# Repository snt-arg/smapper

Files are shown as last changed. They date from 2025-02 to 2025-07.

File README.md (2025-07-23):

<div align="center">
  <h1>🗺️ SMapper: A Portable Multimodal Sensing Platform</h1>
</div>

SMapper is a portable multimodal sensing platform designed for robotics research. It is equipped with an on-board computer, a 3D LiDAR, a set of 4 RGB cameras and a depth camera.

For more information, please visit the online documentation [here](https://snt-arg.github.io/smapper_docs/)

> [!NOTE]
> This device is the result of a Master's thesis conducted by Pedro Soares.

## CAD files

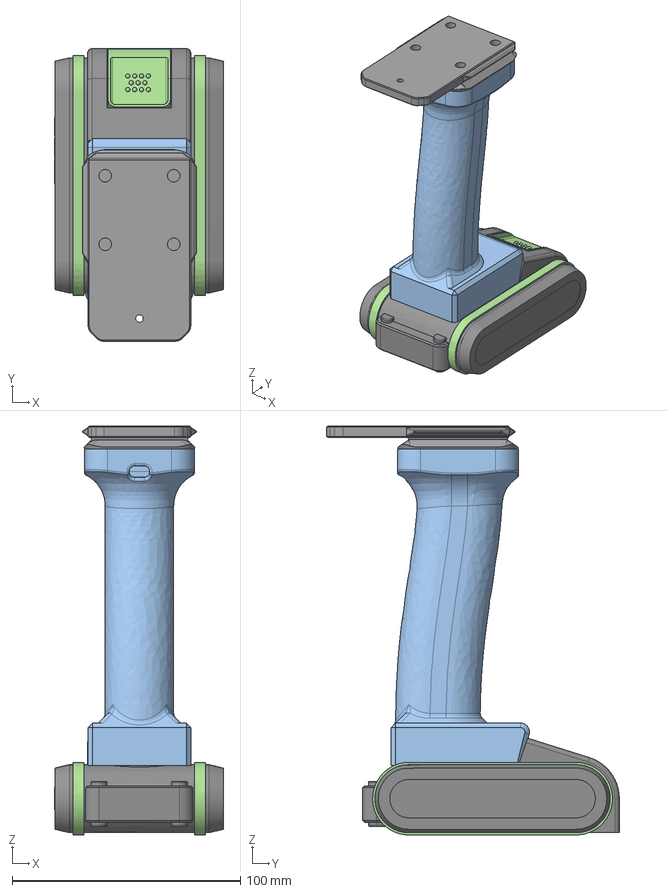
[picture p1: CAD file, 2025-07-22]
hardware/STEP/Battery Handle Assembly.step
74.0 x 128.1 x 179.0 mm
Works 20v Battery v2 v1 x 5
Locking base
Text - 20V x 3
Handle

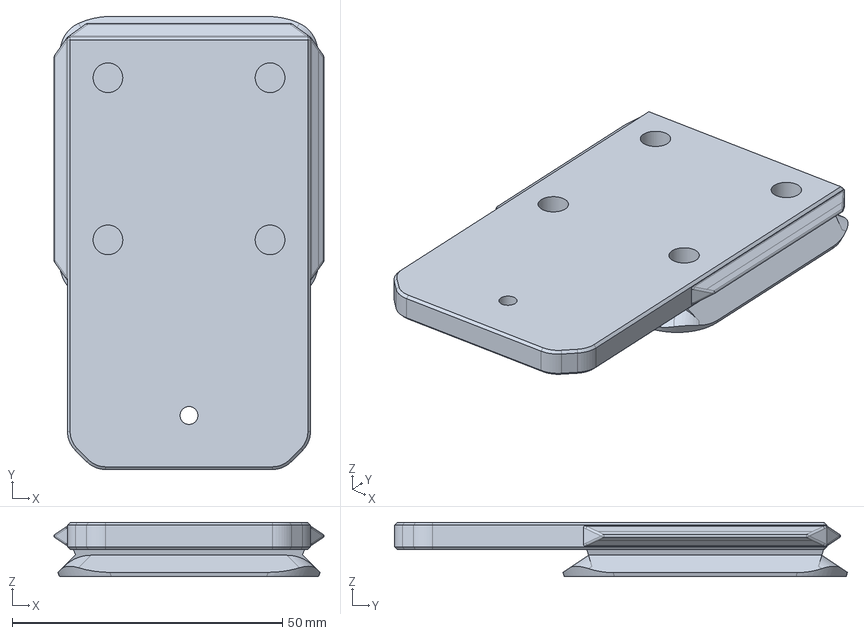
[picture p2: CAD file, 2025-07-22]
hardware/STEP/DovetailMale.step
49.9 x 83.8 x 10.0 mm

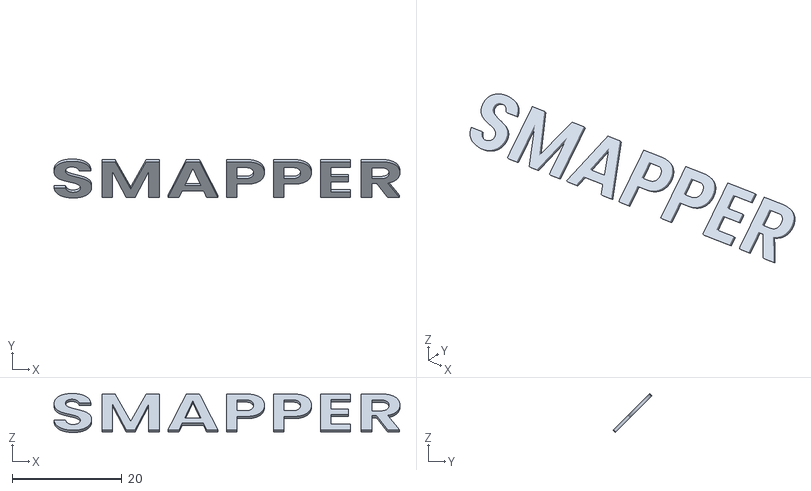
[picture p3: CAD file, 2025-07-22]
hardware/STL/EnclosureLetters.stl
63.2 x 7.14 x 7.14

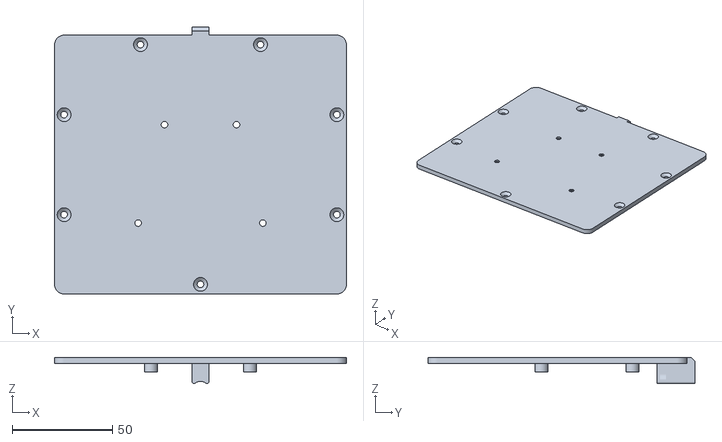
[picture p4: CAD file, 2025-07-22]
hardware/STL/EnclosureTopPlateBasic.stl
146.0 x 133.4 x 13.1

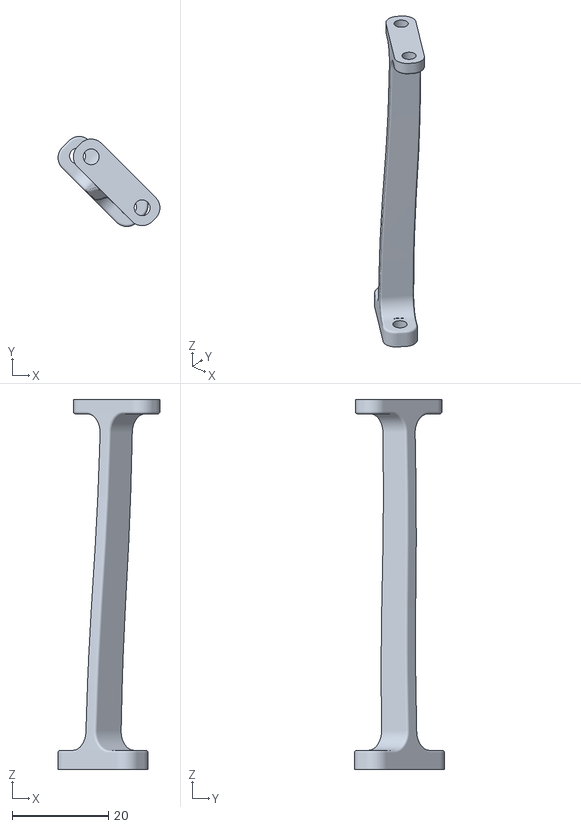
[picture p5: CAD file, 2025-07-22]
hardware/STL/LidarCageFrontLeg.stl
21.2 x 18.7 x 77.0

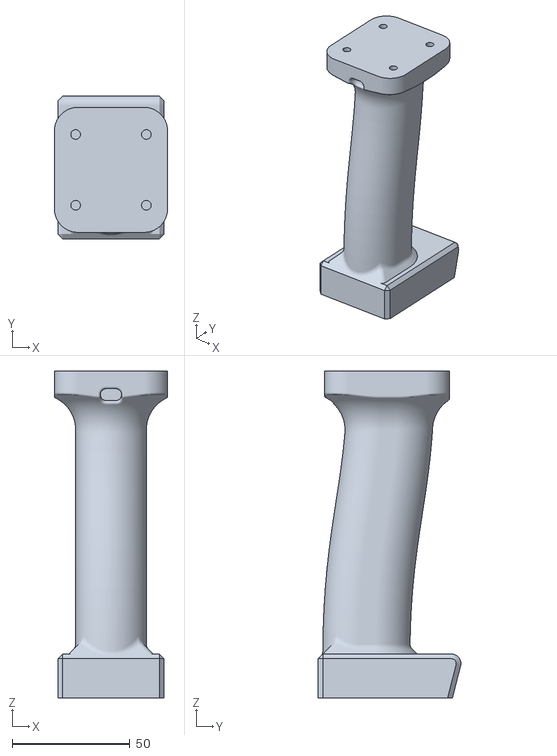
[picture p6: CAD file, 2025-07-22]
hardware/STL/Handle.stl
48.0 x 60.6 x 138.6

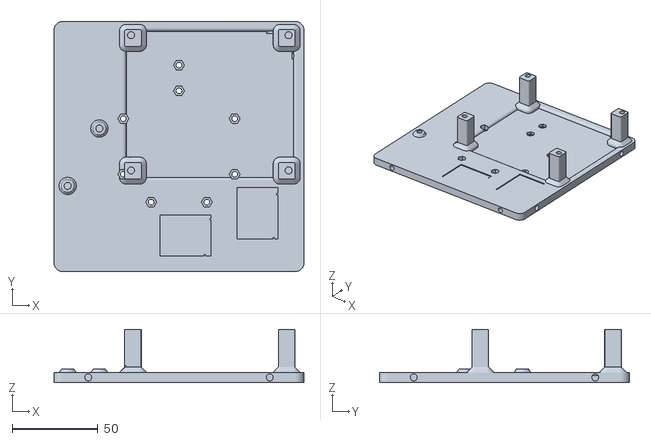
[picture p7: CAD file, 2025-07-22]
hardware/STL/EnclosureBasePlate.stl
146.0 x 146.0 x 31.0

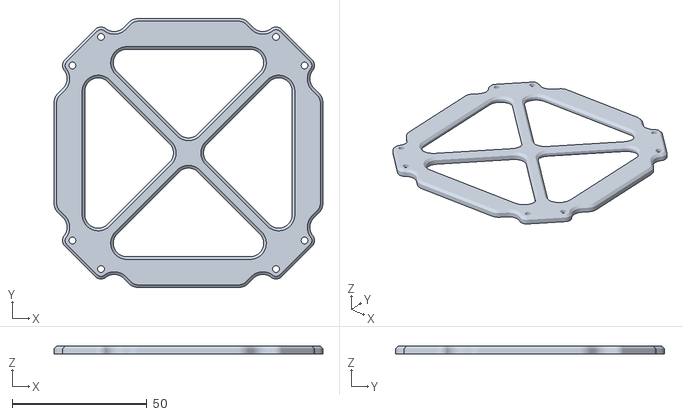
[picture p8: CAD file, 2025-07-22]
hardware/STL/LidarCageTopPlate.stl
100.0 x 100.0 x 3.00

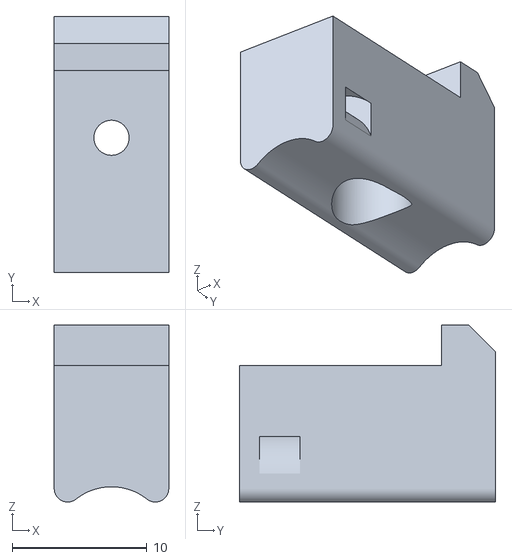
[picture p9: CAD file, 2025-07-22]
hardware/STL/EnclosureOusterCableSupport-MetalPlate.stl
8.50 x 19.0 x 13.1

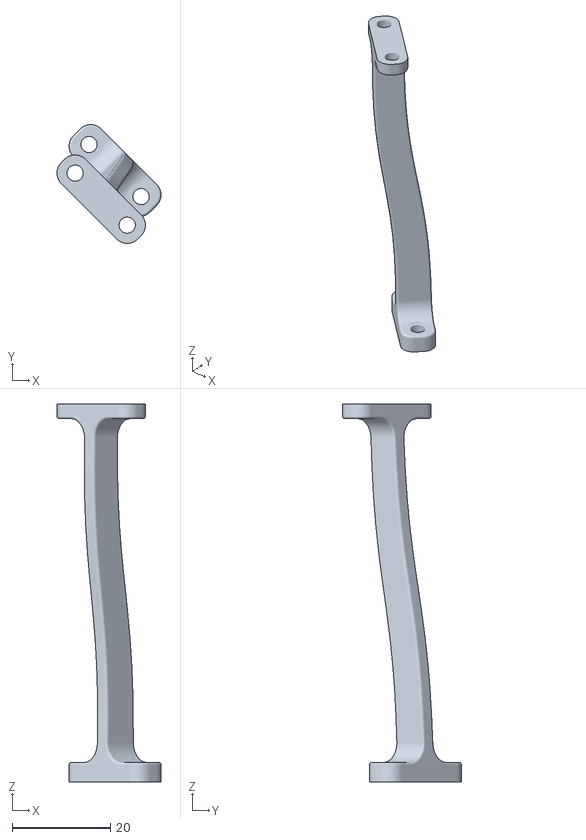
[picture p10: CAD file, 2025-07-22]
hardware/STL/LidarCageBackLeg.stl
21.2 x 24.2 x 77.0

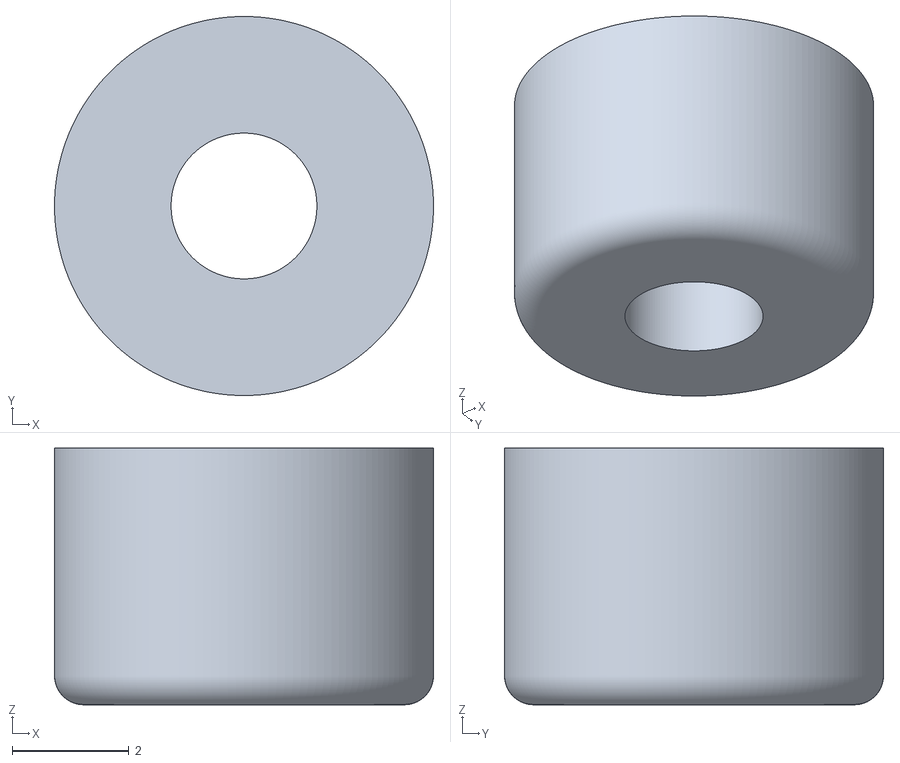
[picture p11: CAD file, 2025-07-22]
hardware/STL/EnclosureOusterInterfaceBoxSpacer-MetalPlate.stl
6.50 x 6.50 x 4.40

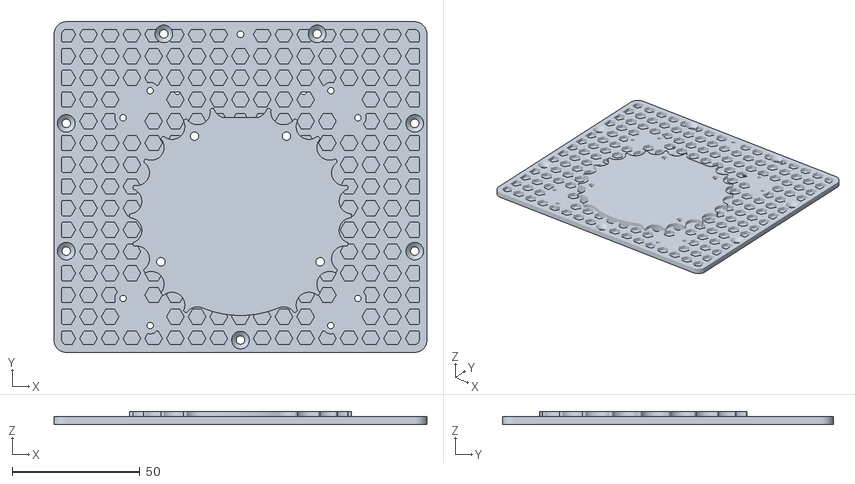
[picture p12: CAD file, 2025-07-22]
hardware/STL/EnclosureTopPlateMetal.stl
146.0 x 129.4 x 5.00

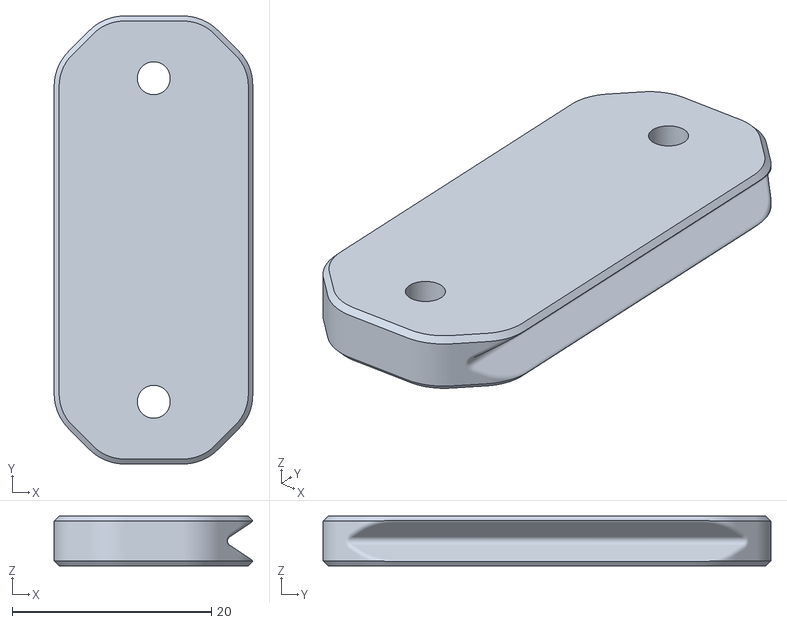
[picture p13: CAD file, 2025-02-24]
hardware/STL/DovetailFemale.stl
20.0 x 45.0 x 5.00

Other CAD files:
hardware/STL/DovetailMale-HandleAttachement.stl

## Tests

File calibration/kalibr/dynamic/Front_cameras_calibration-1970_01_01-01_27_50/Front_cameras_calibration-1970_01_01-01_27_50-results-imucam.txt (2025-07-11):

Calibration results
===================
Normalized Residuals
----------------------------
Reprojection error (cam0):     mean 0.34184654075262016, median 0.30207592490556257, std: 0.2235628586910237
Reprojection error (cam1):     mean 0.32598814781043034, median 0.2877067189554109, std: 0.2435646643541267
Gyroscope error (imu0):        mean 0.47424910224532996, median 0.4057837717863382, std: 0.30432951317669105
Accelerometer error (imu0):    mean 0.379255275407486, median 0.2775870732921912, std: 0.3263196994784197

Residuals
----------------------------
Reprojection error (cam0) [px]:     mean 0.34184654075262016, median 0.30207592490556257, std: 0.2235628586910237
Reprojection error (cam1) [px]:     mean 0.32598814781043034, median 0.2877067189554109, std: 0.2435646643541267
Gyroscope error (imu0) [rad/s]:     mean 0.002020987659160776, median 0.001729226246681794, std: 0.001296884248249636
Accelerometer error (imu0) [m/s^2]: mean 0.07587659234043377, median 0.05553610606084653, std: 0.06528591272296427

Transformation (cam0):
-----------------------
T_ci:  (imu0 to cam0): 
[[ 0.51356612 -0.85804845  0.00164403  0.04847843]
 [ 0.00305803 -0.00008569 -0.99999532 -0.02269768]
 [ 0.85804457  0.51356874  0.00257993 -0.05737305]
 [ 0.          0.          0.          1.        ]]

T_ic:  (cam0 to imu0): 
[[ 0.51356612  0.00305803  0.85804457  0.02440117]
 [-0.85804845 -0.00008569  0.51356874  0.0710599 ]
 [ 0.00164403 -0.99999532  0.00257993 -0.02262926]
 [ 0.          0.          0.          1.        ]]

timeshift cam0 to imu0: [s] (t_imu = t_cam + shift)
-0.0065033632674129736

Transformation (cam1):
-----------------------
T_ci:  (imu0 to cam1): 
[[-0.5225031  -0.85262566  0.00447069 -0.04215714]
 [ 0.00649127 -0.00922106 -0.99993642 -0.02326244]
 [ 0.85261267 -0.52244086  0.01035265 -0.05087947]
 [ 0.          0.          0.          1.        ]]

T_ic:  (cam1 to imu0): 
[[-0.5225031   0.00649127  0.85261267  0.02150425]
 [-0.85262566 -0.00922106 -0.52244086 -0.06274027]
 [ 0.00447069 -0.99993642  0.01035265 -0.02254575]
 [ 0.          0.          0.          1.        ]]

timeshift cam1 to imu0: [s] (t_imu = t_cam + shift)
-0.006169286615626142

Baselines:
----------
Baseline (cam0 to cam1): 
[[ 0.46326158 -0.00599544 -0.88620131 -0.11559549]
 [ 0.00960188  0.99995238 -0.00174562 -0.00113147]
 [ 0.88616957 -0.00770052  0.46329709 -0.06743359]
 [ 0.          0.          0.          1.        ]]
baseline norm:  0.1338315566766952 [m]

Gravity vector in target coords: [m/s^2]
[ 0.01558945 -9.80647147  0.03601555]

Calibration configuration
=========================

cam0
-----
  Camera model: pinhole
  Focal length: [390.2060154022514, 395.24663009853367]
  Principal point: [310.491848714209, 238.02716133642798]
  Distortion model: radtan
  Distortion coefficients: [-0.312301672337043, 0.07057178098208847, 0.0018492338710132529, 0.008018336283615833]
  Type: aprilgrid
  Tags: 
    Rows: 6
    Cols: 6
    Size: 0.088 [m]
    Spacing 0.026399999999999996 [m]

cam1
-----
  Camera model: pinhole
  Focal length: [388.7577664315519, 395.6330495290041]
  Principal point: [336.2011129197593, 234.25459097630343]
  Distortion model: radtan
  Distortion coefficients: [-0.3097449824046875, 0.06842377582678051, 0.001677201986316969, -0.009541678657139735]
  Type: aprilgrid
  Tags: 
    Rows: 6
    Cols: 6
    Size: 0.088 [m]
    Spacing 0.026399999999999996 [m]

IMU configuration
=================

IMU0:
 ----------------------------
  Model: calibrated
  Update rate: 100
  Accelerometer:
    Noise density: 0.02000673352767714 
    Noise density (discrete): 0.2000673352767714 
    Random walk: 0.001224627431466927
  Gyroscope:
    Noise density: 0.0004261447516911305
    Noise density (discrete): 0.004261447516911304 
    Random walk: 2.14534407581717e-05
  T_ib (imu0 to imu0)
    [[1. 0. 0. 0.]
     [0. 1. 0. 0.]
     [0. 0. 1. 0.]
     [0. 0. 0. 1.]]
  time offset with respect to IMU0: 0.0 [s]

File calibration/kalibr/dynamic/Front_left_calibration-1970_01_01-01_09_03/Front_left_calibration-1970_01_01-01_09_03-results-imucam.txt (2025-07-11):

Calibration results
===================
Normalized Residuals
----------------------------
Reprojection error (cam0):     mean 0.26060557996282646, median 0.20807890414653282, std: 0.2698895346148151
Gyroscope error (imu0):        mean 0.520950274873999, median 0.41702240385027334, std: 0.5225403509815032
Accelerometer error (imu0):    mean 0.4189901473808183, median 0.3091509583148264, std: 0.7002739312179902

Residuals
----------------------------
Reprojection error (cam0) [px]:     mean 0.26060557996282646, median 0.20807890414653282, std: 0.2698895346148151
Gyroscope error (imu0) [rad/s]:     mean 0.0022200022552960642, median 0.0017771190873841305, std: 0.002226778281176088
Accelerometer error (imu0) [m/s^2]: mean 0.08382624229370203, median 0.06185100842830754, std: 0.14010193938257237

Transformation (cam0):
-----------------------
T_ci:  (imu0 to cam0): 
[[ 0.49748779 -0.86747035 -0.00104492  0.03373449]
 [-0.01415871 -0.0069155  -0.99987585 -0.03365464]
 [ 0.86735542  0.49744082 -0.01572264 -0.08937043]
 [ 0.          0.          0.          1.        ]]

T_ic:  (cam0 to imu0): 
[[ 0.49748779 -0.01415871  0.86735542  0.06025692]
 [-0.86747035 -0.0069155   0.49744082  0.07348743]
 [-0.00104492 -0.99987585 -0.01572264 -0.03502035]
 [ 0.          0.          0.          1.        ]]

timeshift cam0 to imu0: [s] (t_imu = t_cam + shift)
-0.0059641504083725524

Gravity vector in target coords: [m/s^2]
[ 0.02839863 -9.80650808 -0.00396582]

Calibration configuration
=========================

cam0
-----
  Camera model: pinhole
  Focal length: [392.8114151560641, 392.88374894018546]
  Principal point: [322.4666924919608, 248.22708354340855]
  Distortion model: radtan
  Distortion coefficients: [-0.3420086542144001, 0.10879941637207781, -0.0003229586599770064, -0.0004542659834325975]
  Type: aprilgrid
  Tags: 
    Rows: 6
    Cols: 6
    Size: 0.088 [m]
    Spacing 0.026399999999999996 [m]

IMU configuration
=================

IMU0:
 ----------------------------
  Model: calibrated
  Update rate: 100
  Accelerometer:
    Noise density: 0.02000673352767714 
    Noise density (discrete): 0.2000673352767714 
    Random walk: 0.001224627431466927
  Gyroscope:
    Noise density: 0.0004261447516911305
    Noise density (discrete): 0.004261447516911304 
    Random walk: 2.14534407581717e-05
  T_ib (imu0 to imu0)
    [[1. 0. 0. 0.]
     [0. 1. 0. 0.]
     [0. 0. 1. 0.]
     [0. 0. 0. 1.]]
  time offset with respect to IMU0: 0.0 [s]

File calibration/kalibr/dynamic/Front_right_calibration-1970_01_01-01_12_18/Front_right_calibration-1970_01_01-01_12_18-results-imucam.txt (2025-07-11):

Calibration results
===================
Normalized Residuals
----------------------------
Reprojection error (cam0):     mean 0.2501017272288519, median 0.20435315907673826, std: 0.23580107694945515
Gyroscope error (imu0):        mean 0.4809681975749314, median 0.38047904428295, std: 0.519651119200483
Accelerometer error (imu0):    mean 0.37301568213336955, median 0.2775017337619058, std: 0.47576498837658127

Residuals
----------------------------
Reprojection error (cam0) [px]:     mean 0.2501017272288519, median 0.20435315907673826, std: 0.23580107694945515
Gyroscope error (imu0) [rad/s]:     mean 0.002049620731268997, median 0.0016213914784963632, std: 0.0022144659715770784
Accelerometer error (imu0) [m/s^2]: mean 0.07462825354087042, median 0.05551903240842856, std: 0.09518503344248673

Transformation (cam0):
-----------------------
T_ci:  (imu0 to cam0): 
[[-0.50327608 -0.86410995  0.0052141  -0.01777097]
 [-0.0036913  -0.00388409 -0.99998564 -0.03493967]
 [ 0.8641178  -0.5032881  -0.00123492 -0.07539552]
 [ 0.          0.          0.          1.        ]]

T_ic:  (cam0 to imu0): 
[[-0.50327608 -0.0036913   0.8641178   0.05607793]
 [-0.86410995 -0.00388409 -0.5032881  -0.05343744]
 [ 0.0052141  -0.99998564 -0.00123492 -0.03493962]
 [ 0.          0.          0.          1.        ]]

timeshift cam0 to imu0: [s] (t_imu = t_cam + shift)
-0.006256523372096739

Gravity vector in target coords: [m/s^2]
[ 0.03177853 -9.80649796 -0.0032784 ]

Calibration configuration
=========================

cam0
-----
  Camera model: pinhole
  Focal length: [394.03538004134475, 393.7334645711938]
  Principal point: [321.36647139265347, 242.3425205876215]
  Distortion model: radtan
  Distortion coefficients: [-0.3384351805732969, 0.10202462978420083, -0.00021664571567149408, 0.00014816136191386992]
  Type: aprilgrid
  Tags: 
    Rows: 6
    Cols: 6
    Size: 0.088 [m]
    Spacing 0.026399999999999996 [m]

IMU configuration
=================

IMU0:
 ----------------------------
  Model: calibrated
  Update rate: 100
  Accelerometer:
    Noise density: 0.02000673352767714 
    Noise density (discrete): 0.2000673352767714 
    Random walk: 0.001224627431466927
  Gyroscope:
    Noise density: 0.0004261447516911305
    Noise density (discrete): 0.004261447516911304 
    Random walk: 2.14534407581717e-05
  T_ib (imu0 to imu0)
    [[1. 0. 0. 0.]
     [0. 1. 0. 0.]
     [0. 0. 1. 0.]
     [0. 0. 0. 1.]]
  time offset with respect to IMU0: 0.0 [s]

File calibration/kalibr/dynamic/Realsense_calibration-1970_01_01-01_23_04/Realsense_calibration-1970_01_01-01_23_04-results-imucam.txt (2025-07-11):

Calibration results
===================
Normalized Residuals
----------------------------
Reprojection error (cam0):     mean 0.5175862840394784, median 0.4016384260415893, std: 0.43481792397276503
Gyroscope error (imu0):        mean 1.1389677547282773, median 0.9046086179207804, std: 0.8744231920566471
Accelerometer error (imu0):    mean 0.5351089944562323, median 0.4547291221907699, std: 0.3408890482870113
Gyroscope error (imu1):        mean 0.6610854971174047, median 0.5098315684360688, std: 0.5264413849451314
Accelerometer error (imu1):    mean 0.5570088549998018, median 0.4844410096271336, std: 0.3494258744557038

Residuals
----------------------------
Reprojection error (cam0) [px]:     mean 0.5175862840394784, median 0.4016384260415893, std: 0.43481792397276503
Gyroscope error (imu0) [rad/s]:     mean 0.0048536513102288605, median 0.003854942148615076, std: 0.0037263085405194545
Accelerometer error (imu0) [m/s^2]: mean 0.10705783060349101, median 0.0909764437494527, std: 0.068200763515817
Gyroscope error (imu1) [rad/s]:     mean 0.013583283782897138, median 0.010475478445289198, std: 0.010816759341948135
Accelerometer error (imu1) [m/s^2]: mean 0.05703254391163071, median 0.049602269167092594, std: 0.035777970762712524

Transformation (cam0):
-----------------------
T_ci:  (imu0 to cam0): 
[[-0.01472734 -0.99975055 -0.01679123  0.03993824]
 [-0.05130052  0.01752643 -0.99852946 -0.11186068]
 [ 0.99857467 -0.01384428 -0.05154584 -0.12417108]
 [ 0.          0.          0.          1.        ]]

T_ic:  (cam0 to imu0): 
[[-0.01472734 -0.05130052  0.99857467  0.11884377]
 [-0.99975055  0.01752643 -0.01384428  0.04016973]
 [-0.01679123 -0.99852946 -0.05154584 -0.11742608]
 [ 0.          0.          0.          1.        ]]

timeshift cam0 to imu0: [s] (t_imu = t_cam + shift)
0.023254825488191154

Gravity vector in target coords: [m/s^2]
[-0.03418676 -9.80649041  0.00019449]

Calibration configuration
=========================

cam0
-----
  Camera model: pinhole
  Focal length: [581.1303265478947, 581.467887625284]
  Principal point: [343.6828365250734, 273.8167096163441]
  Distortion model: radtan
  Distortion coefficients: [0.08382439416254173, -0.12969976579269596, 0.01050246520757501, 0.00914606335682514]
  Type: aprilgrid
  Tags: 
    Rows: 6
    Cols: 6
    Size: 0.088 [m]
    Spacing 0.026399999999999996 [m]

IMU configuration
=================

IMU0:
 ----------------------------
  Model: calibrated
  Update rate: 100
  Accelerometer:
    Noise density: 0.02000673352767714 
    Noise density (discrete): 0.2000673352767714 
    Random walk: 0.001224627431466927
  Gyroscope:
    Noise density: 0.0004261447516911305
    Noise density (discrete): 0.004261447516911304 
    Random walk: 2.14534407581717e-05
  T_ib (imu0 to imu0)
    [[1. 0. 0. 0.]
     [0. 1. 0. 0.]
     [0. 0. 1. 0.]
     [0. 0. 0. 1.]]
  time offset with respect to IMU0: 0.0 [s]

IMU1:
 ----------------------------
  Model: calibrated
  Update rate: 400
  Accelerometer:
    Noise density: 0.005119536556707974 
    Noise density (discrete): 0.10239073113415947 
    Random walk: 0.0007446449364276494
  Gyroscope:
    Noise density: 0.0010273469802412588
    Noise density (discrete): 0.020546939604825173 
    Random walk: 3.8743601798420855e-05
  T_ib (imu0 to imu1)
    [[-0.00631694 -0.99992376  0.01061034  0.02102086]
     [-0.02330857 -0.01046043 -0.99967359 -0.08087949]
     [ 0.99970836 -0.00656219 -0.02324071 -0.05481246]
     [ 0.          0.          0.          1.        ]]
  time offset with respect to IMU0: 0.0 [s]

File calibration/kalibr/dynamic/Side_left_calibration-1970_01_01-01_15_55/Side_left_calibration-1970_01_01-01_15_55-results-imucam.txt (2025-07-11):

Calibration results
===================
Normalized Residuals
----------------------------
Reprojection error (cam0):     mean 0.22282056384570034, median 0.1757992654703525, std: 0.29874572304403346
Gyroscope error (imu0):        mean 0.4287617694887986, median 0.3320653721138685, std: 0.662608514190408
Accelerometer error (imu0):    mean 0.3836267350760264, median 0.25065936497100366, std: 1.099740978916369

Residuals
----------------------------
Reprojection error (cam0) [px]:     mean 0.22282056384570034, median 0.1757992654703525, std: 0.29874572304403346
Gyroscope error (imu0) [rad/s]:     mean 0.0018271457779345374, median 0.0014150791554468731, std: 0.002823671407481003
Accelerometer error (imu0) [m/s^2]: mean 0.07675117862758851, median 0.0501487512119164, std: 0.22002224714646593

Transformation (cam0):
-----------------------
T_ci:  (imu0 to cam0): 
[[ 0.99992889  0.0063852  -0.01007176  0.06002549]
 [-0.00999619 -0.01175799 -0.99988091 -0.03853333]
 [-0.00650286  0.99991049 -0.01169333 -0.09837282]
 [ 0.          0.          0.          1.        ]]

T_ic:  (cam0 to imu0): 
[[ 0.99992889 -0.00999619 -0.00650286 -0.06104612]
 [ 0.0063852  -0.01175799  0.99991049  0.09752766]
 [-0.01007176 -0.99988091 -0.01169333 -0.03907448]
 [ 0.          0.          0.          1.        ]]

timeshift cam0 to imu0: [s] (t_imu = t_cam + shift)
-0.007034674133095784

Gravity vector in target coords: [m/s^2]
[ 0.01238823 -9.80654163 -0.00327489]

Calibration configuration
=========================

cam0
-----
  Camera model: pinhole
  Focal length: [390.96396644777445, 390.67392021681087]
  Principal point: [314.9531860050542, 246.83142317585296]
  Distortion model: radtan
  Distortion coefficients: [-0.3387266411322653, 0.10577531579622686, -0.0007865133327070225, -0.0002981926316847731]
  Type: aprilgrid
  Tags: 
    Rows: 6
    Cols: 6
    Size: 0.088 [m]
    Spacing 0.026399999999999996 [m]

IMU configuration
=================

IMU0:
 ----------------------------
  Model: calibrated
  Update rate: 100
  Accelerometer:
    Noise density: 0.02000673352767714 
    Noise density (discrete): 0.2000673352767714 
    Random walk: 0.001224627431466927
  Gyroscope:
    Noise density: 0.0004261447516911305
    Noise density (discrete): 0.004261447516911304 
    Random walk: 2.14534407581717e-05
  T_ib (imu0 to imu0)
    [[1. 0. 0. 0.]
     [0. 1. 0. 0.]
     [0. 0. 1. 0.]
     [0. 0. 0. 1.]]
  time offset with respect to IMU0: 0.0 [s]

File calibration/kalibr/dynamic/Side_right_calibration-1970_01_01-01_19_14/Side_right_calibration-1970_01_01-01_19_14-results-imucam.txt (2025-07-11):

Calibration results
===================
Normalized Residuals
----------------------------
Reprojection error (cam0):     mean 0.2618088893407216, median 0.20773128685452819, std: 0.30983709842938073
Gyroscope error (imu0):        mean 0.49595888905192326, median 0.362949622898755, std: 0.6008593907722937
Accelerometer error (imu0):    mean 0.400606018492705, median 0.26986919091364786, std: 0.7827538633036482

Residuals
----------------------------
Reprojection error (cam0) [px]:     mean 0.2618088893407216, median 0.20773128685452819, std: 0.30983709842938073
Gyroscope error (imu0) [rad/s]:     mean 0.0021135027762404076, median 0.0015466907692657937, std: 0.00256053075881943
Accelerometer error (imu0) [m/s^2]: mean 0.0801481786156725, median 0.053992009899391805, std: 0.15660347960875906

Transformation (cam0):
-----------------------
T_ci:  (imu0 to cam0): 
[[-0.99991602  0.00734013  0.01068063 -0.06410733]
 [-0.01072126 -0.00551832 -0.9999273  -0.0419488 ]
 [-0.00728066 -0.99995783  0.00559656 -0.06768289]
 [ 0.          0.          0.          1.        ]]

T_ic:  (cam0 to imu0): 
[[-0.99991602 -0.01072126 -0.00728066 -0.06504447]
 [ 0.00734013 -0.00551832 -0.99995783 -0.06744097]
 [ 0.01068063 -0.9999273   0.00559656 -0.04088226]
 [ 0.          0.          0.          1.        ]]

timeshift cam0 to imu0: [s] (t_imu = t_cam + shift)
-0.005539621203977999

Gravity vector in target coords: [m/s^2]
[ 0.00764259 -9.806534   -0.0159784 ]

Calibration configuration
=========================

cam0
-----
  Camera model: pinhole
  Focal length: [392.59904852429565, 392.50624902130187]
  Principal point: [323.4648160379844, 238.86345955126814]
  Distortion model: radtan
  Distortion coefficients: [-0.3358266646965245, 0.10180877221204587, -8.911335434829571e-05, -0.0002897227755827224]
  Type: aprilgrid
  Tags: 
    Rows: 6
    Cols: 6
    Size: 0.088 [m]
    Spacing 0.026399999999999996 [m]

IMU configuration
=================

IMU0:
 ----------------------------
  Model: calibrated
  Update rate: 100
  Accelerometer:
    Noise density: 0.02000673352767714 
    Noise density (discrete): 0.2000673352767714 
    Random walk: 0.001224627431466927
  Gyroscope:
    Noise density: 0.0004261447516911305
    Noise density (discrete): 0.004261447516911304 
    Random walk: 2.14534407581717e-05
  T_ib (imu0 to imu0)
    [[1. 0. 0. 0.]
     [0. 1. 0. 0.]
     [0. 0. 1. 0.]
     [0. 0. 0. 1.]]
  time offset with respect to IMU0: 0.0 [s]

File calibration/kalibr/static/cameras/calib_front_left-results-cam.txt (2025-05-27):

Calibration results 
====================
Camera-system parameters:
cam0 (/camera/front_left/image_raw):
    type: <class 'aslam_cv.libaslam_cv_python.DistortedPinholeCameraGeometry'>
    distortion: [-0.31554921  0.07903554  0.00045287 -0.00026353] +- [0.00127792 0.0007724  0.00015435 0.00017054]
    projection: [392.22459932 391.80472572 318.50651627 244.96194446] +- [0.76665211 0.71702384 0.52765083 0.54922336]
    reprojection error: [0.000004, 0.000000] +- [0.461770, 0.369325]

Target configuration
====================

  Type: aprilgrid
  Tags: 
    Rows: 6
    Cols: 6
    Size: 0.088 [m]
    Spacing 0.026399999999999996 [m]

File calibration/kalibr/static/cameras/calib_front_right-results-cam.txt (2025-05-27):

Calibration results 
====================
Camera-system parameters:
cam0 (/camera/front_right/image_raw):
    type: <class 'aslam_cv.libaslam_cv_python.DistortedPinholeCameraGeometry'>
    distortion: [-0.31957898  0.0806469  -0.00080197  0.00035669] +- [0.00196815 0.00109669 0.00023507 0.00018263]
    projection: [393.06641796 392.98060045 323.6422896  244.46900485] +- [1.10550742 1.10277156 0.45731078 0.50662746]
    reprojection error: [-0.000002, 0.000001] +- [0.439053, 0.347816]

Target configuration
====================

  Type: aprilgrid
  Tags: 
    Rows: 6
    Cols: 6
    Size: 0.088 [m]
    Spacing 0.026399999999999996 [m]

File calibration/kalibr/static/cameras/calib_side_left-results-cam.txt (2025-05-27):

Calibration results 
====================
Camera-system parameters:
cam0 (/camera/side_left/image_raw):
    type: <class 'aslam_cv.libaslam_cv_python.DistortedPinholeCameraGeometry'>
    distortion: [-0.32201131  0.08680743  0.00003892  0.00006133] +- [0.00230067 0.00141515 0.00020115 0.00016923]
    projection: [390.45597408 390.22416046 322.84506513 237.46722073] +- [1.24246316 1.23915271 0.46138078 0.49184567]
    reprojection error: [-0.000001, 0.000001] +- [0.379369, 0.301230]

Target configuration
====================

  Type: aprilgrid
  Tags: 
    Rows: 6
    Cols: 6
    Size: 0.088 [m]
    Spacing 0.026399999999999996 [m]

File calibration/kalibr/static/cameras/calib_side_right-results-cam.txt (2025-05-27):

Calibration results 
====================
Camera-system parameters:
cam0 (/camera/side_right/image_raw):
    type: <class 'aslam_cv.libaslam_cv_python.DistortedPinholeCameraGeometry'>
    distortion: [-0.33239045  0.09437278 -0.00022199 -0.00004808] +- [0.00231786 0.00153081 0.00019502 0.00017768]
    projection: [394.88099696 394.54001341 312.80370879 244.83934767] +- [1.24934965 1.21584631 0.44448264 0.46093973]
    reprojection error: [-0.000001, 0.000000] +- [0.321834, 0.280067]

Target configuration
====================

  Type: aprilgrid
  Tags: 
    Rows: 6
    Cols: 6
    Size: 0.088 [m]
    Spacing 0.026399999999999996 [m]

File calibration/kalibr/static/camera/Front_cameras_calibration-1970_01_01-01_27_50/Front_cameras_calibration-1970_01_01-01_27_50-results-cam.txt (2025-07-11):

Calibration results 
====================
Camera-system parameters:
cam0 (/camera/front_left/image_raw):
    type: <class 'aslam_cv.libaslam_cv_python.DistortedPinholeCameraGeometry'>
    distortion: [-0.31230167  0.07057178  0.00184923  0.00801834] +- [0.00126208 0.00051542 0.00013316 0.00059402]
    projection: [390.2060154  395.2466301  310.49184871 238.02716134] +- [0.55242442 0.35097369 0.55214465 0.68708279]
    reprojection error: [-0.000010, 0.000006] +- [0.382468, 0.290356]

cam1 (/camera/front_right/image_raw):
    type: <class 'aslam_cv.libaslam_cv_python.DistortedPinholeCameraGeometry'>
    distortion: [-0.30974498  0.06842378  0.0016772  -0.00954168] +- [0.00121402 0.00050326 0.00012854 0.00057584]
    projection: [388.75776643 395.63304953 336.20111292 234.25459098] +- [0.55597776 0.35273907 0.56267278 0.68814268]
    reprojection error: [0.000153, 0.000003] +- [0.367816, 0.279198]

baseline T_1_0:
    q: [ 0.00174048  0.51802358 -0.00455874  0.85535242] +- [0.00165184 0.00230806 0.00115898]
    t: [-0.11559549 -0.00113147 -0.06743359] +- [0.00122582 0.00048352 0.00188532]

Target configuration
====================

  Type: aprilgrid
  Tags: 
    Rows: 6
    Cols: 6
    Size: 0.088 [m]
    Spacing 0.026399999999999996 [m]

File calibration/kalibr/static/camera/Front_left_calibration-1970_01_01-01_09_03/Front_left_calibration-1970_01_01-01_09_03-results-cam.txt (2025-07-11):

Calibration results 
====================
Camera-system parameters:
cam0 (/camera/front_left/image_raw):
    type: <class 'aslam_cv.libaslam_cv_python.DistortedPinholeCameraGeometry'>
    distortion: [-0.34200865  0.10879942 -0.00032296 -0.00045427] +- [0.00195367 0.00188139 0.00026371 0.00022789]
    projection: [392.81141516 392.88374894 322.46669249 248.22708354] +- [1.3515694  1.31849869 0.91096937 1.01371328]
    reprojection error: [-0.000001, 0.000001] +- [0.165781, 0.149661]

Target configuration
====================

  Type: aprilgrid
  Tags: 
    Rows: 6
    Cols: 6
    Size: 0.088 [m]
    Spacing 0.026399999999999996 [m]

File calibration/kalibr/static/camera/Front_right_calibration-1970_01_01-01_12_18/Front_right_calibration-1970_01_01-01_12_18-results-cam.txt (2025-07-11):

Calibration results 
====================
Camera-system parameters:
cam0 (/camera/front_right/image_raw):
    type: <class 'aslam_cv.libaslam_cv_python.DistortedPinholeCameraGeometry'>
    distortion: [-0.33843518  0.10202463 -0.00021665  0.00014816] +- [0.00194309 0.00165542 0.00025234 0.0002699 ]
    projection: [394.03538004 393.73346457 321.36647139 242.34252059] +- [1.20665013 1.18499328 0.75401862 0.78724871]
    reprojection error: [0.000001, -0.000001] +- [0.192999, 0.148572]

Target configuration
====================

  Type: aprilgrid
  Tags: 
    Rows: 6
    Cols: 6
    Size: 0.088 [m]
    Spacing 0.026399999999999996 [m]

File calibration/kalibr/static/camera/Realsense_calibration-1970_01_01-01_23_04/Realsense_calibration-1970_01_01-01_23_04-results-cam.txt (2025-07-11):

Calibration results 
====================
Camera-system parameters:
cam0 (/camera/realsense/color/image_raw):
    type: <class 'aslam_cv.libaslam_cv_python.DistortedPinholeCameraGeometry'>
    distortion: [ 0.08382439 -0.12969977  0.01050247  0.00914606] +- [0.00450935 0.00947031 0.00069214 0.00065312]
    projection: [581.13032655 581.46788763 343.68283653 273.81670962] +- [2.93513911 2.9163151  1.41110842 1.42472265]
    reprojection error: [-0.000001, 0.000002] +- [0.369571, 0.362580]

Target configuration
====================

  Type: aprilgrid
  Tags: 
    Rows: 6
    Cols: 6
    Size: 0.088 [m]
    Spacing 0.026399999999999996 [m]

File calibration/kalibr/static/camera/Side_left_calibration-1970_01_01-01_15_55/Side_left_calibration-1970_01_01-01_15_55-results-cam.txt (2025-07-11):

Calibration results 
====================
Camera-system parameters:
cam0 (/camera/side_left/image_raw):
    type: <class 'aslam_cv.libaslam_cv_python.DistortedPinholeCameraGeometry'>
    distortion: [-0.33872664  0.10577532 -0.00078651 -0.00029819] +- [0.0024488  0.00217458 0.00029019 0.00023065]
    projection: [390.96396645 390.67392022 314.95318601 246.83142318] +- [1.42727856 1.3987448  0.74643177 0.85826905]
    reprojection error: [0.000000, 0.000001] +- [0.152585, 0.130522]

Target configuration
====================

  Type: aprilgrid
  Tags: 
    Rows: 6
    Cols: 6
    Size: 0.088 [m]
    Spacing 0.026399999999999996 [m]

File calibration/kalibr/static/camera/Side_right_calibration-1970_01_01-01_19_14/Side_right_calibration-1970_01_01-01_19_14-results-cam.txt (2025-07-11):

Calibration results 
====================
Camera-system parameters:
cam0 (/camera/side_right/image_raw):
    type: <class 'aslam_cv.libaslam_cv_python.DistortedPinholeCameraGeometry'>
    distortion: [-0.33582666  0.10180877 -0.00008911 -0.00028972] +- [0.00187929 0.00149254 0.00028843 0.00020137]
    projection: [392.59904852 392.50624902 323.46481604 238.86345955] +- [1.43487332 1.41363856 0.8030799  1.00454128]
    reprojection error: [0.000000, 0.000000] +- [0.202043, 0.163921]

Target configuration
====================

  Type: aprilgrid
  Tags: 
    Rows: 6
    Cols: 6
    Size: 0.088 [m]
    Spacing 0.026399999999999996 [m]

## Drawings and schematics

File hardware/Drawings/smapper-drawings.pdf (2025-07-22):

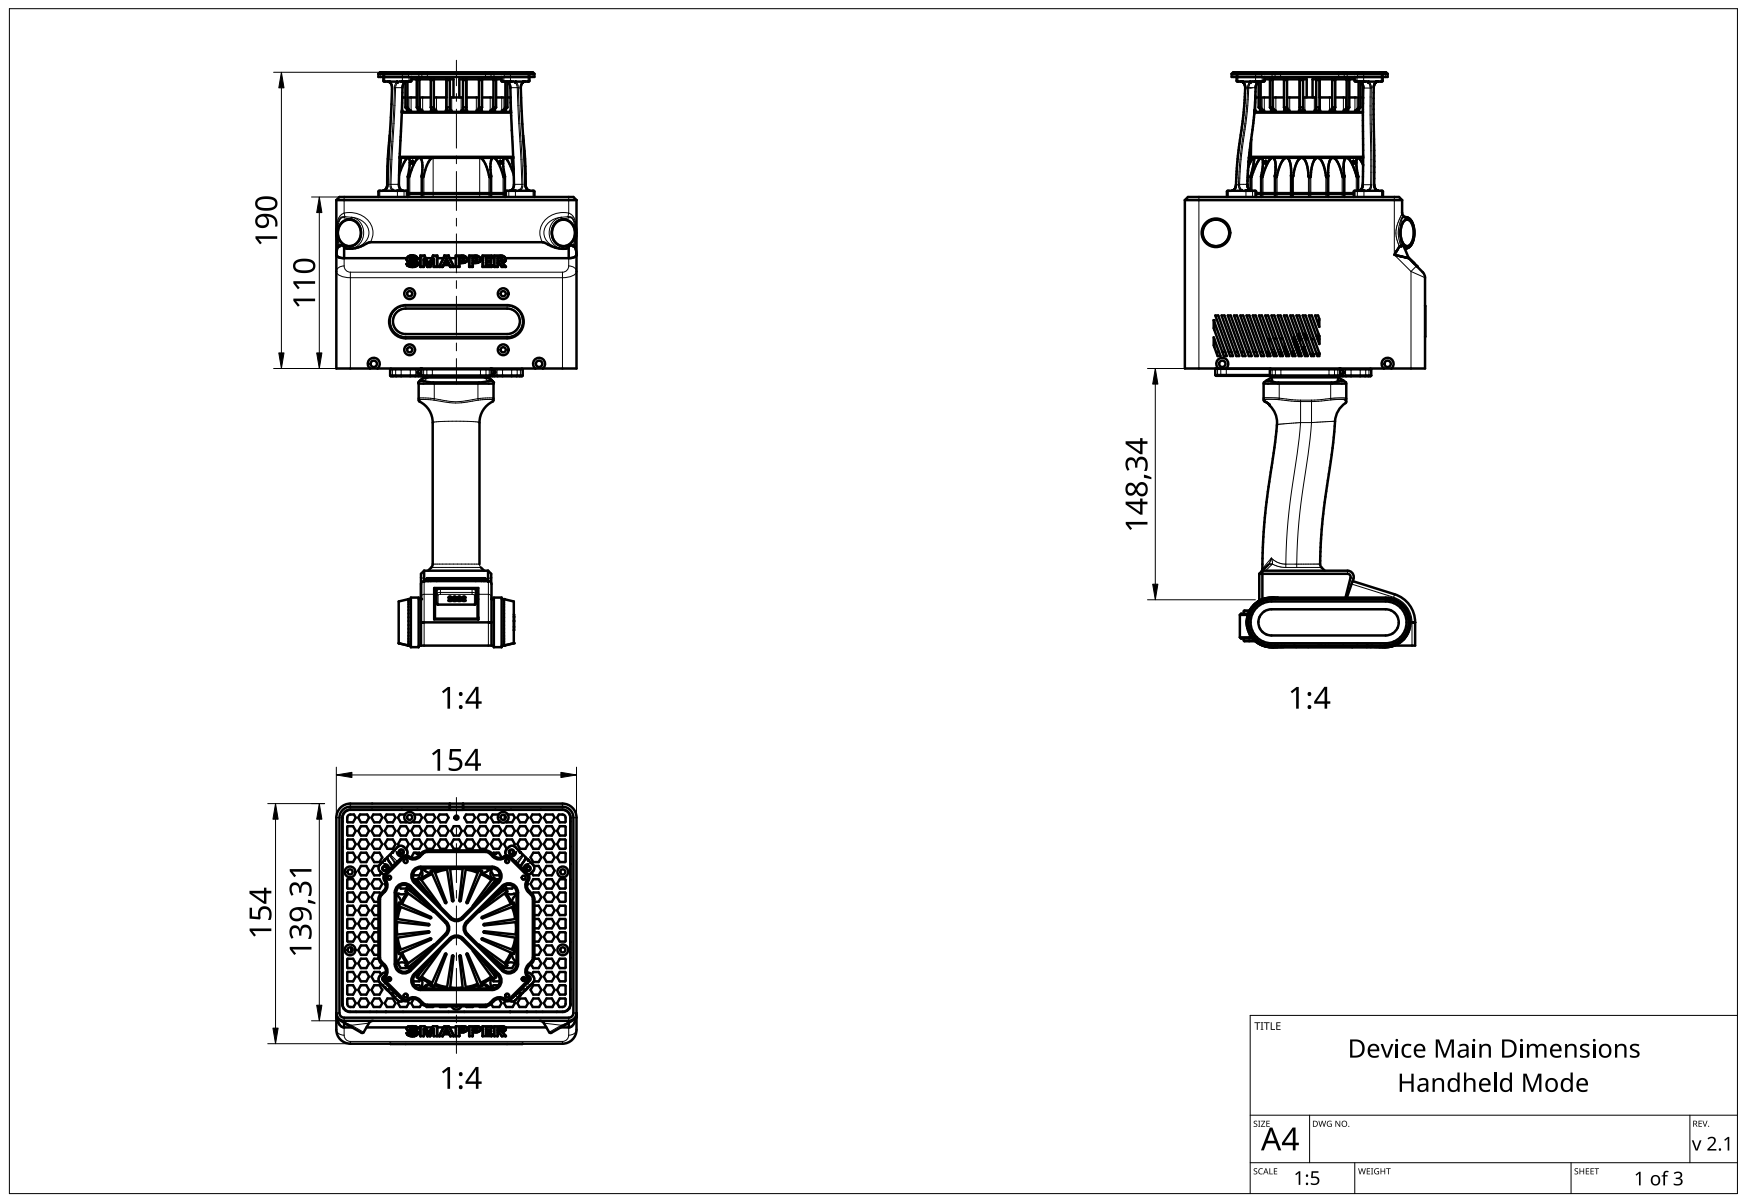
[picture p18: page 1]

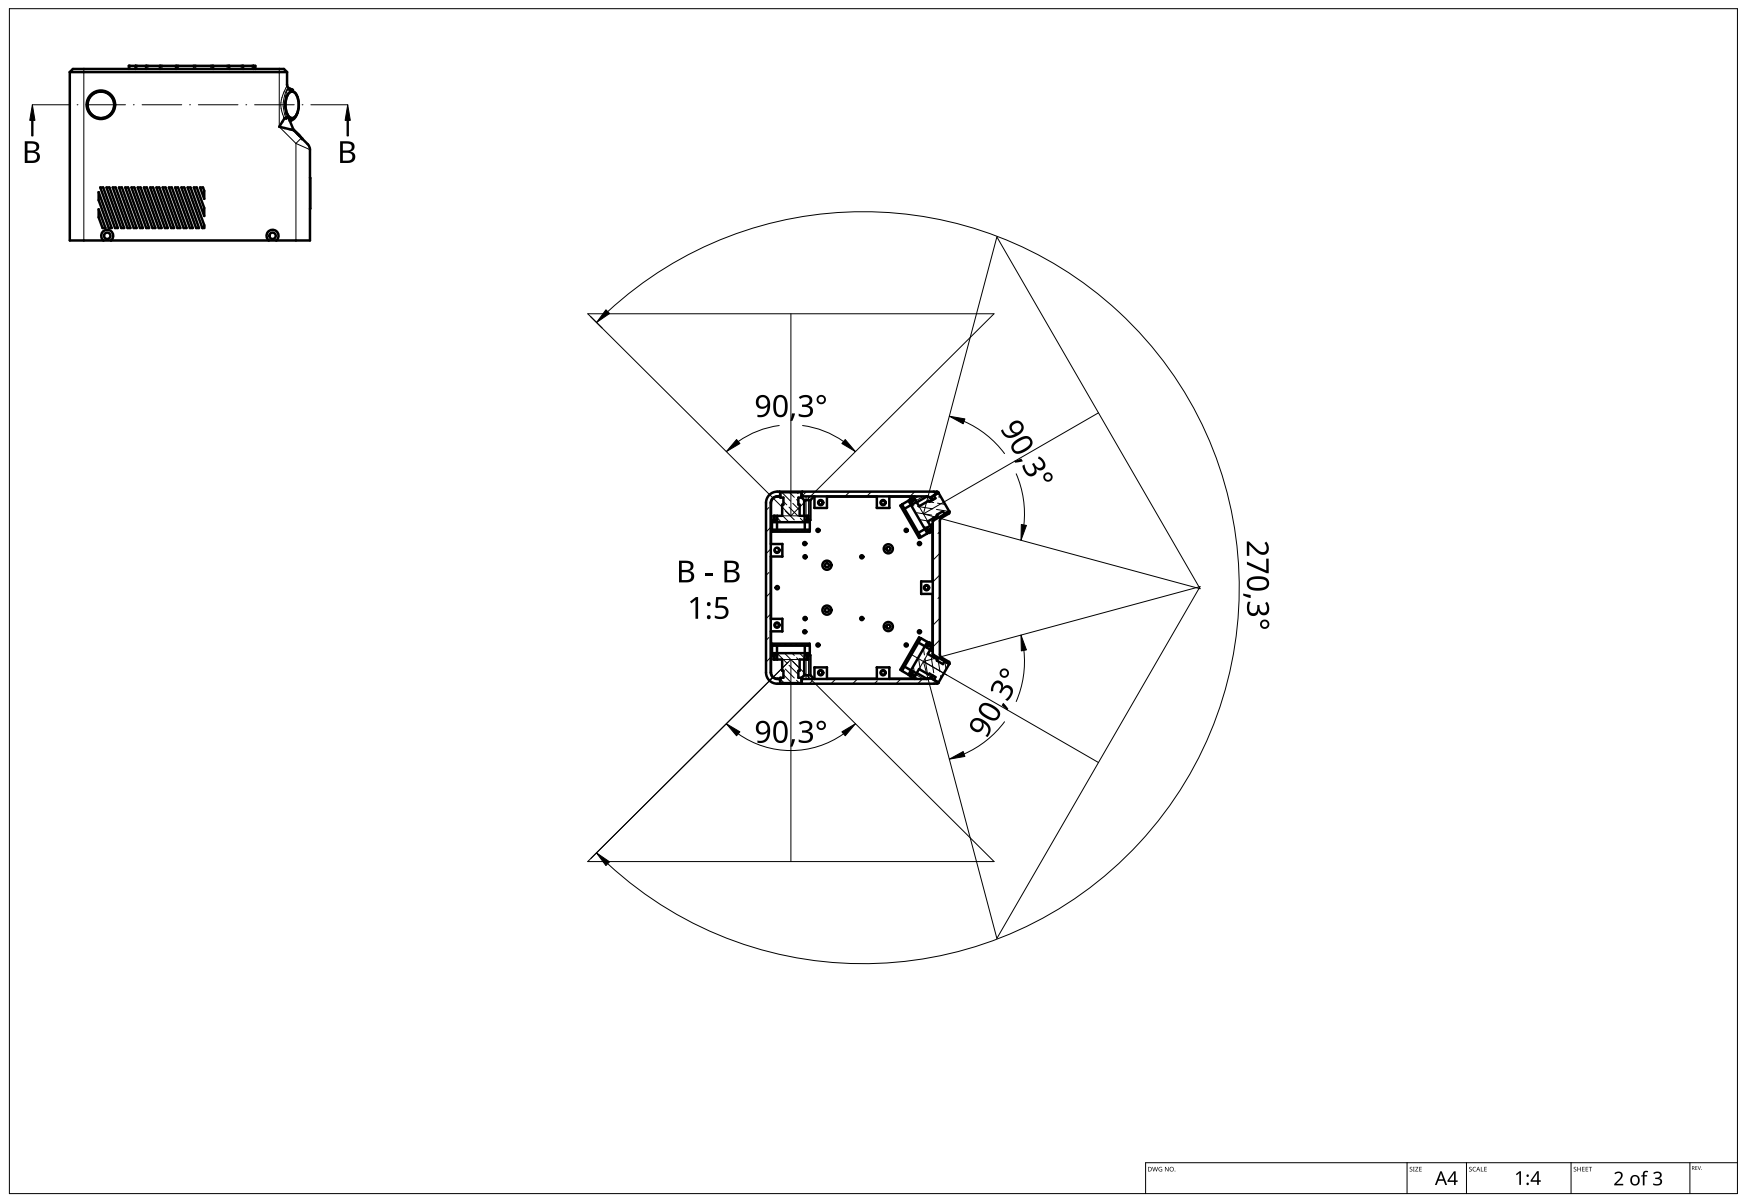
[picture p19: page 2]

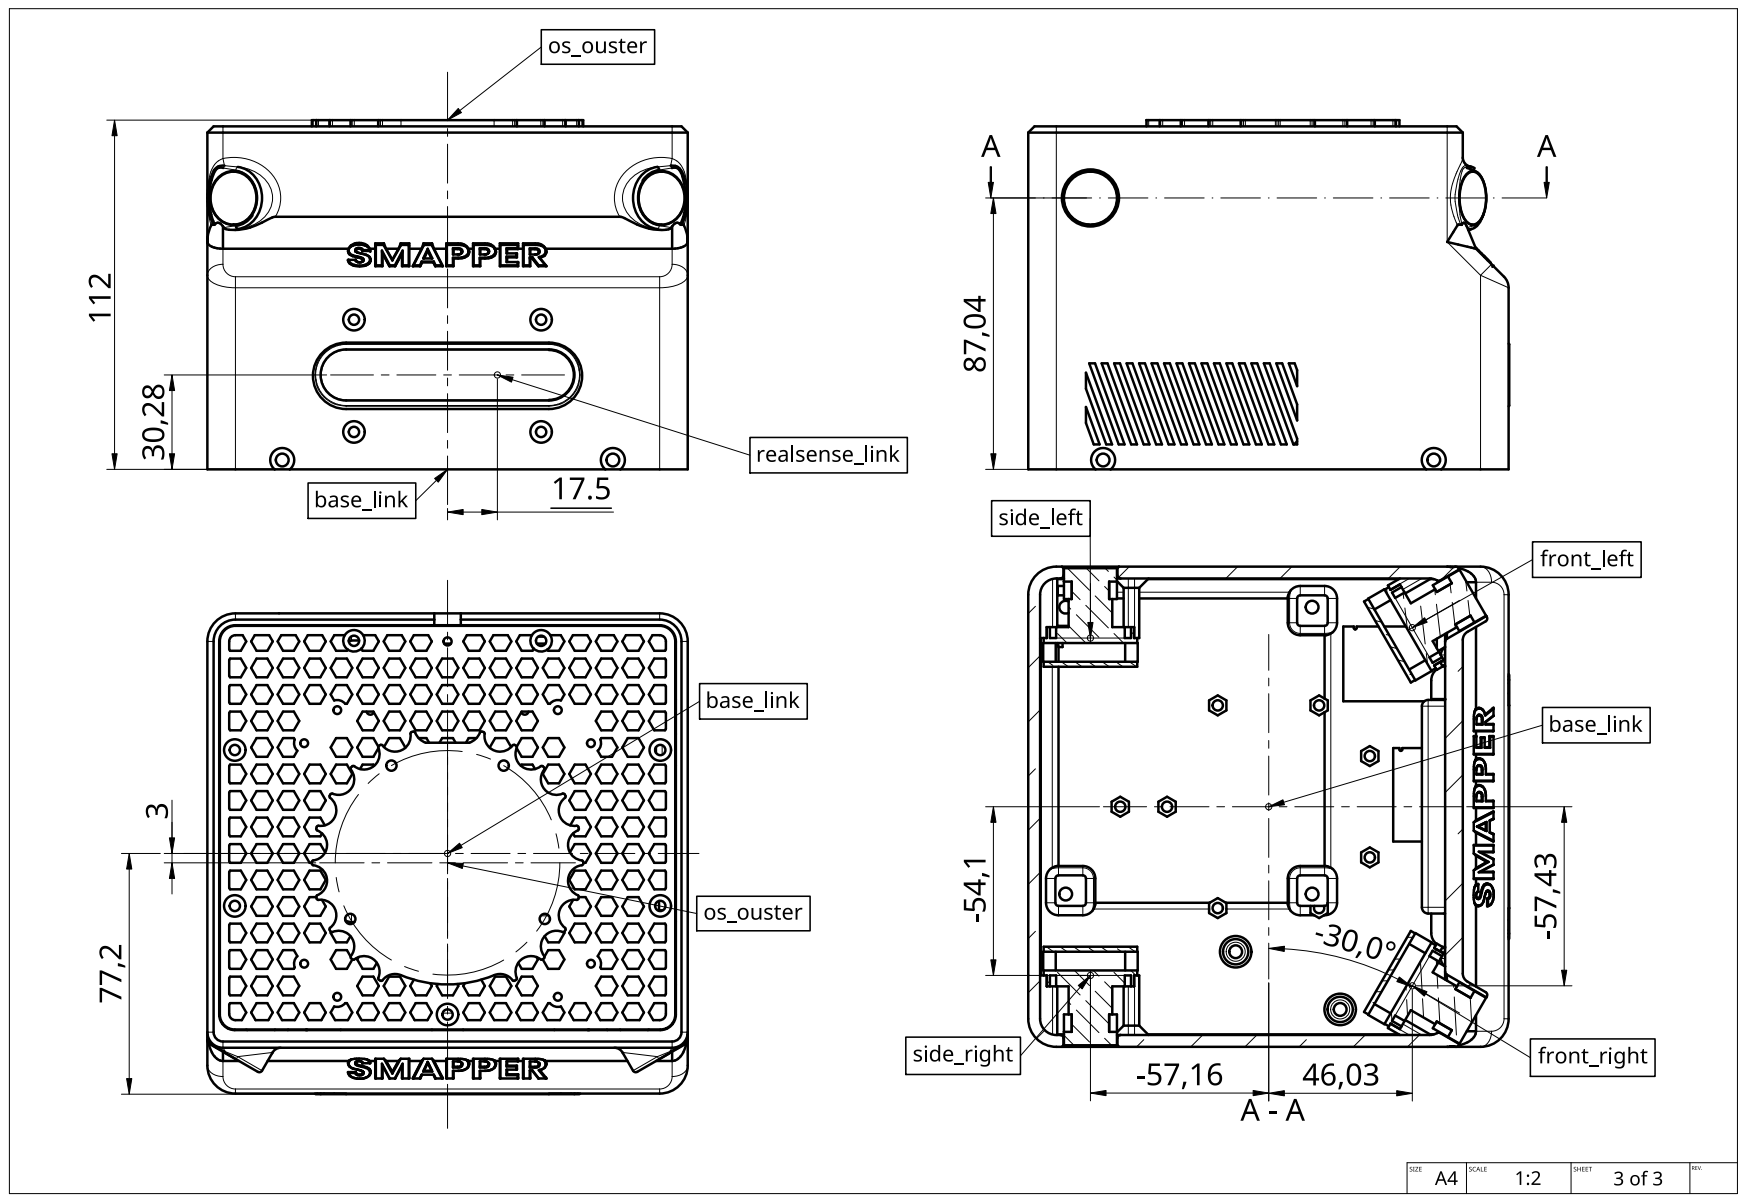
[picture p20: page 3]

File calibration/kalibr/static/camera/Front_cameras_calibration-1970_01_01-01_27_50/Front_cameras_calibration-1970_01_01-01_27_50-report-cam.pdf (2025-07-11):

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

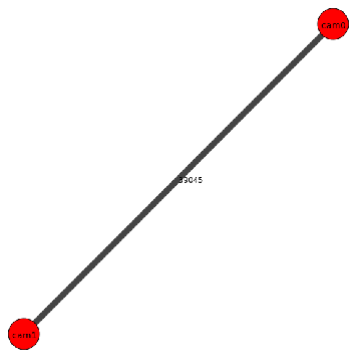
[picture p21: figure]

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

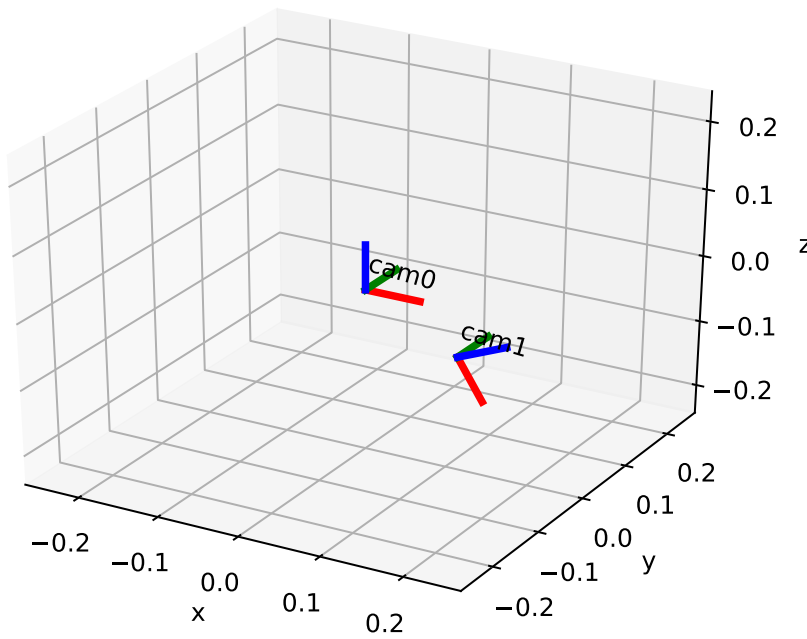
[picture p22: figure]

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

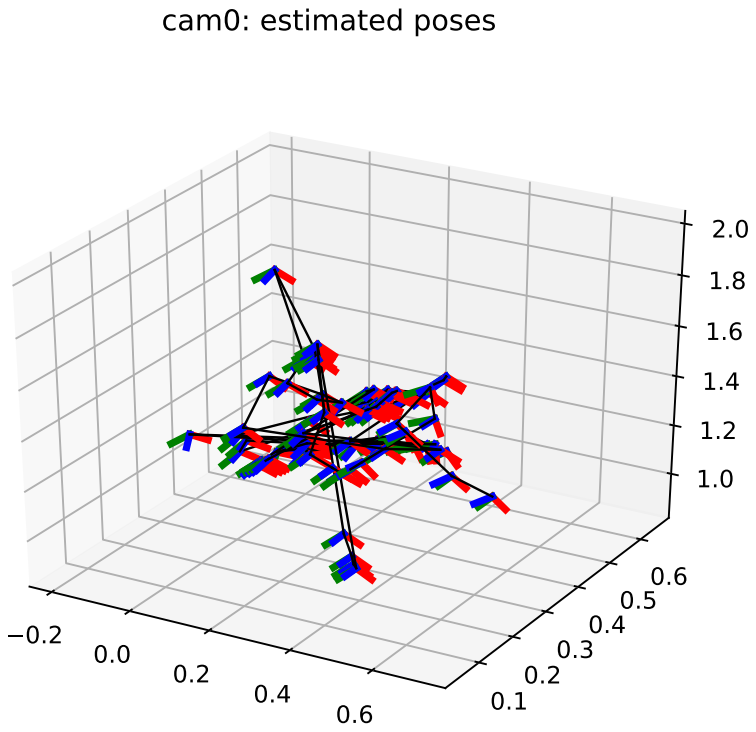
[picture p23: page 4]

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

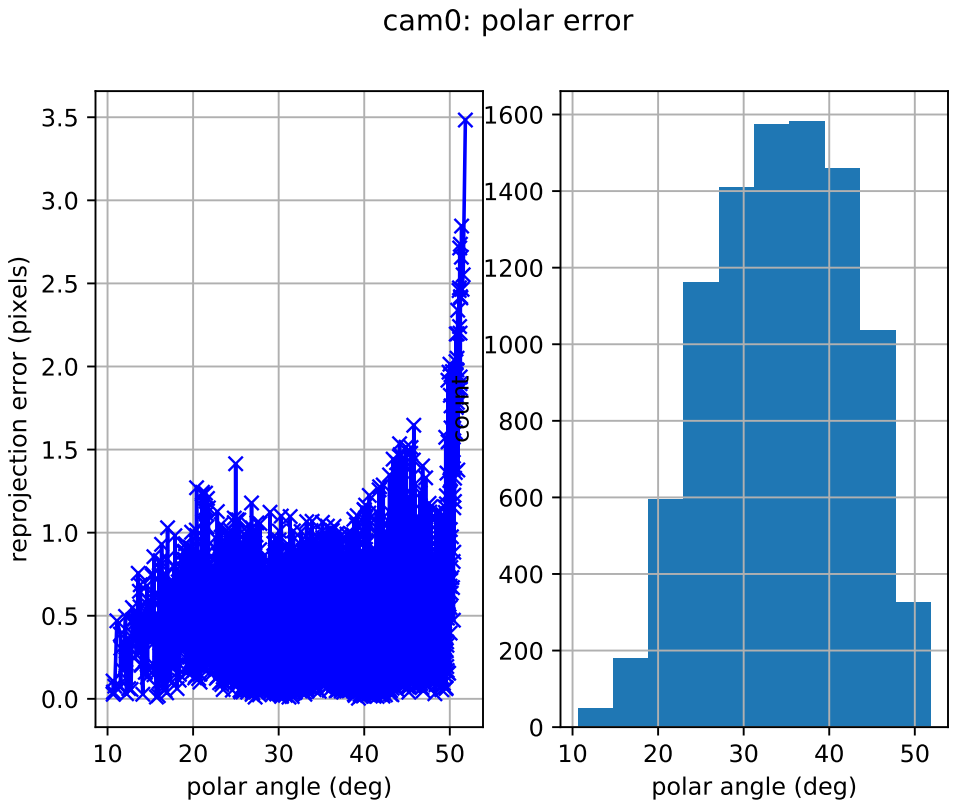
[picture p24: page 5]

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

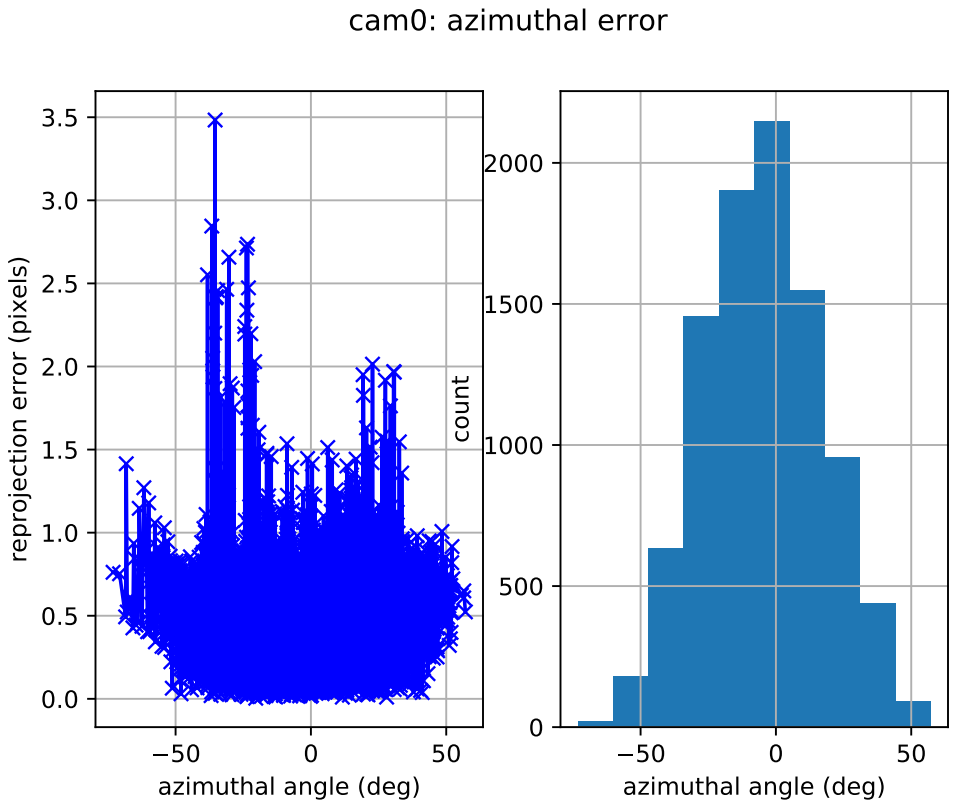
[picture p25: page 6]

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

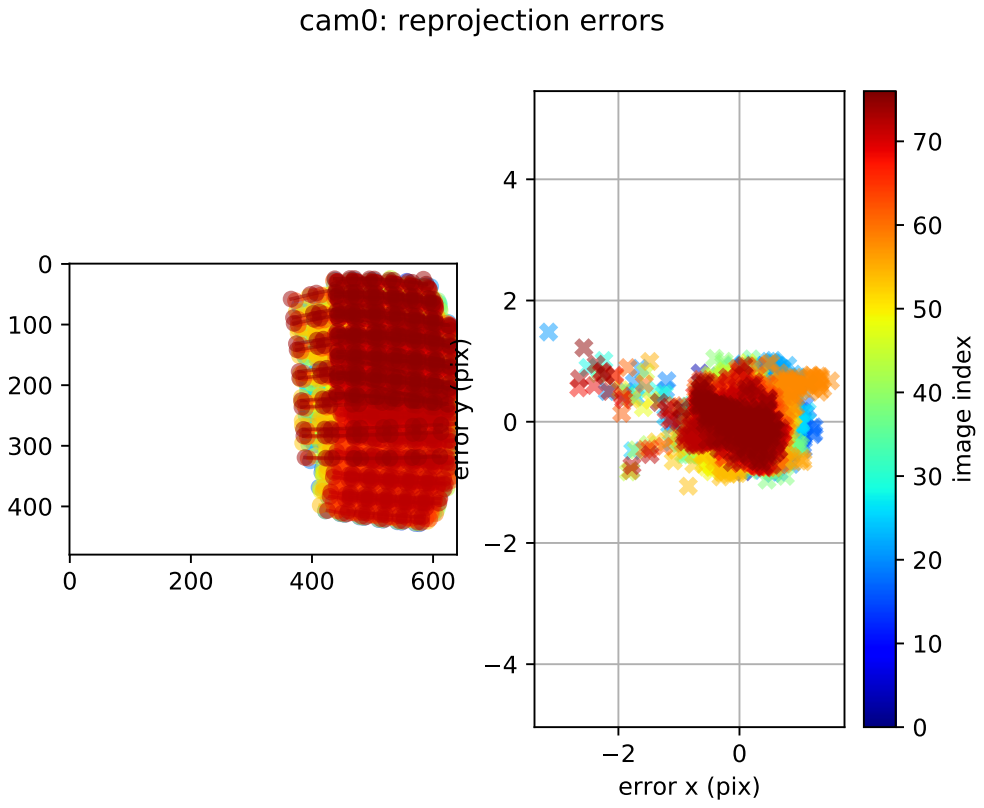
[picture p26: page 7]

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

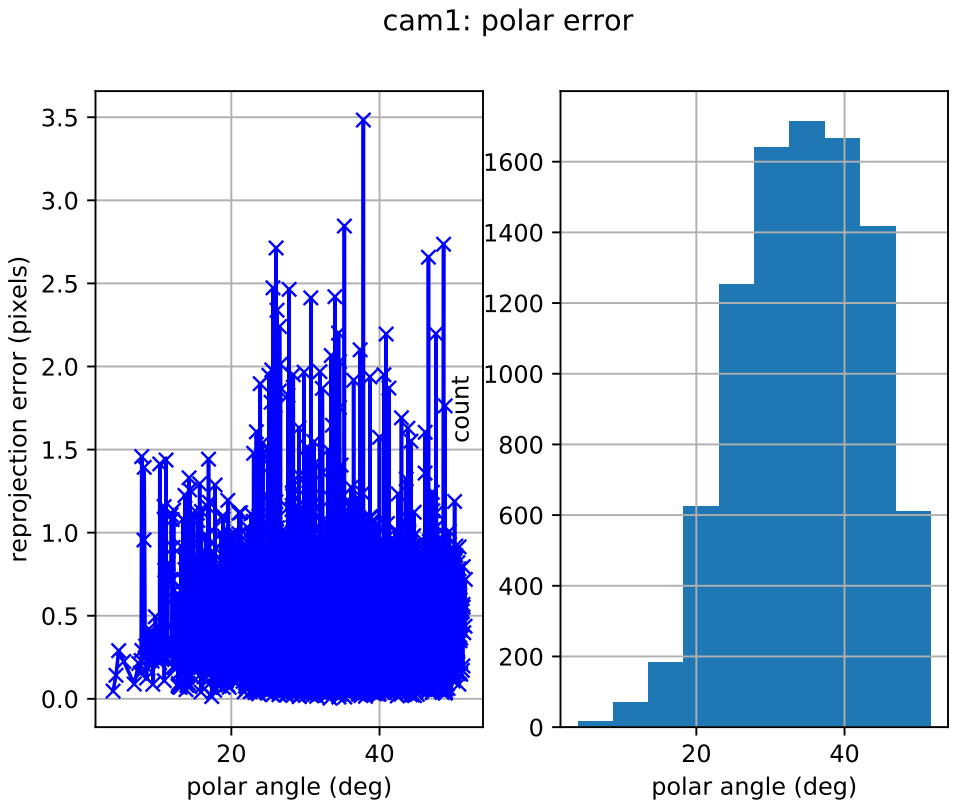
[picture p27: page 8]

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

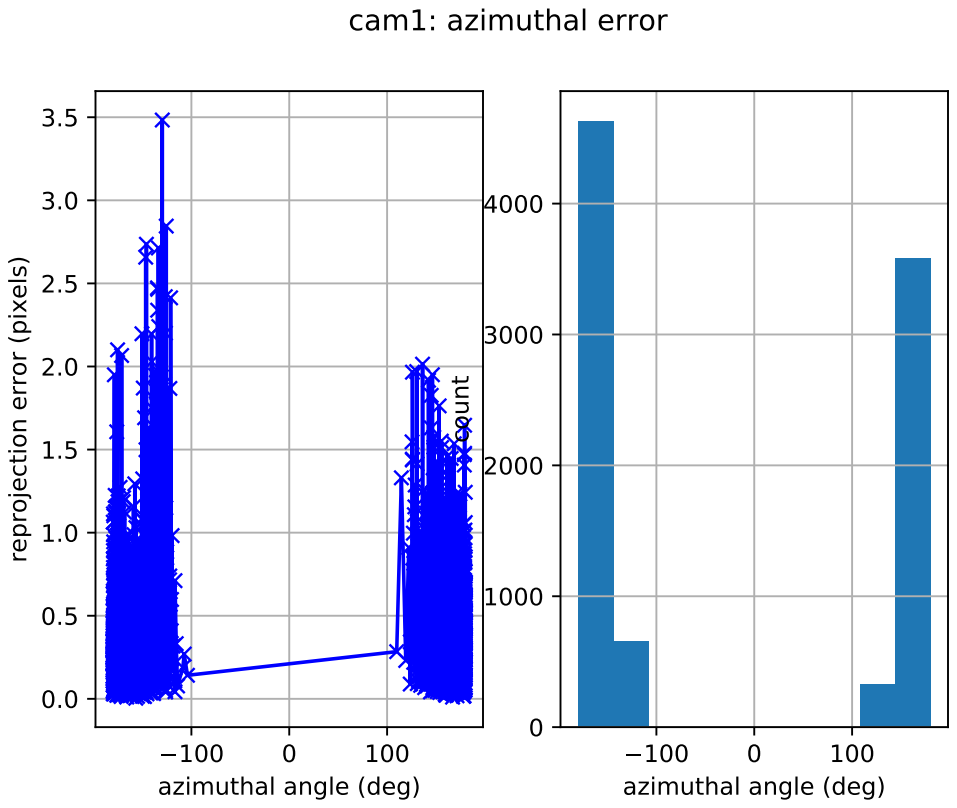
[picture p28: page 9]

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

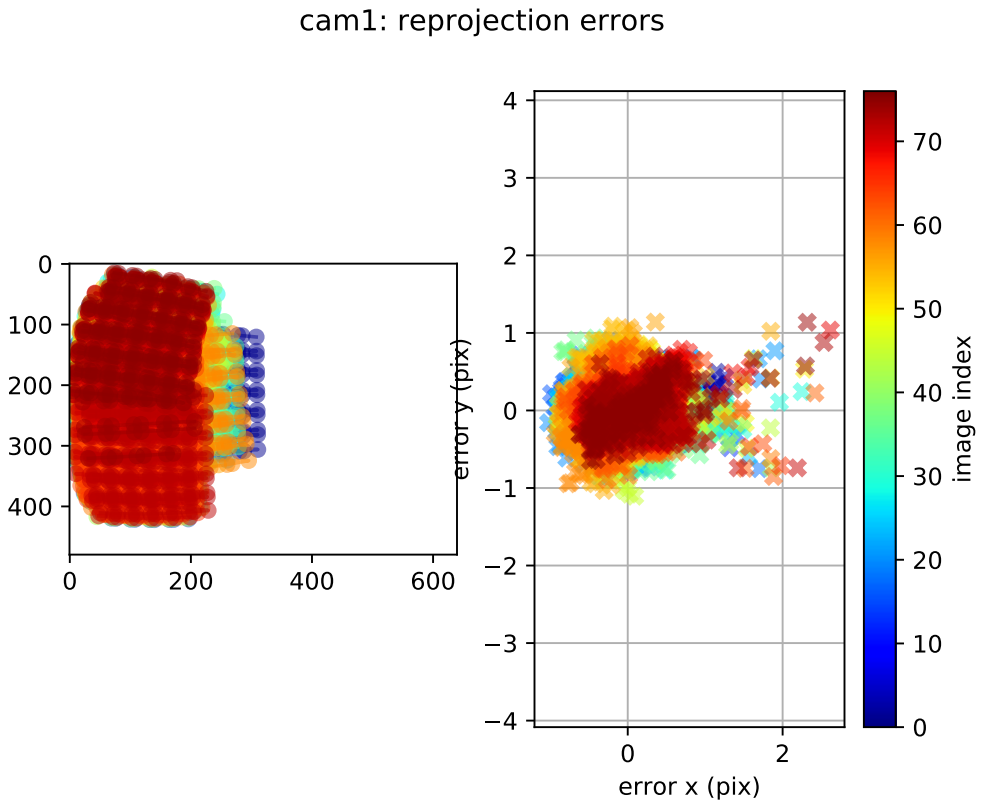
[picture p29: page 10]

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

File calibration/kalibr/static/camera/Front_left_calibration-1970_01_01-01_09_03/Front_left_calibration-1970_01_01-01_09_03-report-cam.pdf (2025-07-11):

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

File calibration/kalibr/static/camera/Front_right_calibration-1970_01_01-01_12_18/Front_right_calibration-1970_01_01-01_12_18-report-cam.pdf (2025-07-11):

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

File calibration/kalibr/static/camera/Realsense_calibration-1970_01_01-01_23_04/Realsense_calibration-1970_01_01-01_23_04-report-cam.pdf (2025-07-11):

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

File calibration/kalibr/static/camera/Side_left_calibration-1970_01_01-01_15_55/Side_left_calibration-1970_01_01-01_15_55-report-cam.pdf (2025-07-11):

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

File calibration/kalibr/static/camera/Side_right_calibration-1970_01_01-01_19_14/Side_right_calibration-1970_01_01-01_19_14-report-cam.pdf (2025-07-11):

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

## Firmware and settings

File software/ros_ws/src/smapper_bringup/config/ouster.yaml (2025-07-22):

ouster/os_driver:
    ros__parameters:
        sensor_hostname: "os-122436001165.local"
        # mtp_main[optional]: if true, then configure and reinit the sensor,
        # otherwise start client with active configuration of sensor
        mtp_main: true
        # lidar_mode[optional]: resolution and rate; possible values: { 512x10,
        # 512x20, 1024x10, 1024x20, 2048x10, 4096x5 }. Leave empty to remain on
        # current the lidar mode.
        lidar_mode: "1024x10"
        # timestamp_mode[optional]: method used to timestamp measurements; possible
        # values:
        # - TIME_FROM_INTERNAL_OSC
        # - TIME_FROM_SYNC_PULSE_IN
        # - TIME_FROM_PTP_1588
        # - TIME_FROM_ROS_TIME: This option uses the time of reception of first
        #                       packet of a LidarScan as the timestamp of the IMU,
        #                       PointCloud2 and LaserScan messages.
        timestamp_mode: "TIME_FROM_ROS_TIME"
        # ptp_utc_tai_offset[optional]: UTC/TAI offset in seconds to apply when
        # TIME_FROM_PTP_1588 timestamp mode is used.
        ptp_utc_tai_offset: -37.0
        udp_profile_lidar: "RNG19_RFL8_SIG16_NIR16"
        metadata: "/home/smapper/smapper/config/os-122436001165-metadata.json"
        lidar_port: 46750
        imu_port: 37267
        sensor_frame: os_sensor
        lidar_frame: os_lidar
        imu_frame: os_imu
        point_cloud_frame: os_lidar
        pub_static_tf: false
        # proc_mask[optional]: use any combination of the 6 flags IMG, PCL, IMU, SCAN
        # RAW and TLM to enable or disable their respective messages.
        # proc_mask: IMU|PCL|SCAN|IMG|RAW|TLM
        proc_mask: IMU|PCL
        # use_system_default_qos[optional]: if false, data are published with sensor
        # data QoS. This is preferrable for production but default QoS is needed for
        # rosbag. See: https://github.com/ros2/rosbag2/issues/125
        use_system_default_qos: true
        point_type: original
        persist_config: false
        attempt_reconnect: true
        max_failed_reconnect_attempts: 20
        min_range: 0.0
        max_range: 1000.0

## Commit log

2025-01-06 chore: create empty folder for cad models
2025-01-08 feat(api): add boiler plate for scan endpoint
2025-02-05 chore: include Argus camera libraries
2025-02-14 chore: remove jetson api headers
2025-02-14 feat: script to view argus camera output using GStream
2025-02-17 chore: create nodes for single and multi camera
2025-02-17 refactor: clean sample code to remove EGL render and not used modes
2025-02-19 feat: simple executable to test multi_camera
    Currently one needs to manually kill the process due to threads not
    being killed
2025-02-20 feat: push processed frames to buffer and make it available on get_frames
    This commit allows a parent node of the class MultiCamera to make use of
    get_frames in order to obtain the processed frames which have been
    converted into cv::Mat.
    Additionally, some refactoring has been made
2025-02-20 feat: create a basic ros2 node to publish a single camera frames
2025-02-20 chore: remove sample example
2025-02-21 build: add camera_info_manager dependency
2025-02-21 feat: set sensor mode from config
    Additionally, changed the type of vector for the ids to work with
    get_parameters from ros
2025-02-21 feat: add support for camera info
2025-02-22 chore: add CADs for handle & realsense attachments
    [AttachementCoupler.stl, AttachementSlider.stl, RealsenseAttachement.stl]
2025-02-24 chore: update camera calibration parameters
2025-02-26 fix: frame ids typo on front right camera
2025-02-26 feat: include /camera also in camera info topic
2025-02-26 fix: front right info config wrong camera name
2025-02-27 chore(calibration): obtain better calibration info of cameras
2025-02-27 docs: add calibration command
2025-03-01 chore: create package for camera_lidar_fusion
2025-03-01 feat: basic version with one camera pointcloud colorizer
2025-03-11 chore(bringup): update camera infos and lidar cameras tf
2025-03-13 chore(cad): add shell and top meshes
2025-05-13 chore: change camera infos path
2025-05-13 feat: create separate launch files for each sensor
2025-05-16 feat: helper script to calibrat cameras with kalibr
2025-05-16 chore: update argus camera submodule
2025-05-20 chore: create calibration folder for calibration config files
2025-05-21 add imu calibration and camera
    [allan_variance.csv, calib01_front_left-camchain.yaml, calib01_front_right-camchain.yaml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]
2025-05-27 chore: clean up kalibr files
    [calib01_front_left-camchain.yaml, calib01_front_right-camchain.yaml, calib01_side_left-camchain.yaml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]
2025-05-27 feat: initial implemantation of calibration automated script
2025-05-28 feat: calibration of cameras extrinsics, imu and imu-camera
    [calib02_front_left-camchain-imucam.yaml, calib02_front_left-camchain.yaml, calib02_front_left-imu.yaml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]
2025-06-04 calib: update camera calibration results
    [calib02_front_left-camchain.yaml, calib02_front_right-camchain.yaml, calib02_side_left-camchain.yaml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]
2025-06-06 chore: update to latests calibration results
2025-06-06 feat: use newer camera configuration
2025-06-06 chore: use newer values for transformation between cameras and lidar
2025-06-27 feat: use the values from CAD between lidar base and enclosure base
2025-07-04 chore: update cameras info with latest calibration results
2025-07-04 feat: add sensors transformations from calibration
2025-07-04 chore: add latest calibration results
    [Calibration_Front_Left-1970_01_01-01_14_44-camchain-imucam.yaml, Calibration_Front_Left-1970_01_01-01_14_44-camchain.yaml, Calibration_Front_Left-1970_01_01-01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]
2025-07-04 chore: remove old calibration results
    [allan_variance.csv, calib02_front_left-camchain-imucam.yaml, calib02_front_left-camchain.yaml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]
2025-07-04 fix: use calibration fro bringup config
2025-07-11 add better calibration results
    [Calibration_Front_Left-1970_01_01-01_14_44-camchain-imucam.yaml, Calibration_Front_Left-1970_01_01-01_14_44-camchain.yaml, Calibration_Front_Left-1970_01_01-01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]
2025-07-11 update device tree from new calibration
2025-07-11 chore: update camera infos from new calibration
2025-07-18 config: use device tree to publish ouster tf tree
2025-07-22 chore: restructure project
    [AttachementCoupler.stl, AttachementSlider.stl, RealsenseAttachement.stl]
2025-07-22 chore(ros): update order of cameras based on the new hw layout
2025-07-22 chore(hw): add updated cad files
    [AttachementCoupler.stl, AttachementSlider.stl, Battery Handle Assembly.step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]
